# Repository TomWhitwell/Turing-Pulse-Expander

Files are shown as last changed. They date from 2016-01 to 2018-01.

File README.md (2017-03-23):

# Turing-Pulse-Expander
Rev 2 Turing Pulse Expander 

This is a slightly updated version of the Turing Machine Pulse Expander, with more outputs. It uses SMD components, but is still a very easy build. 

BOM: 

- 1 x 4081 Quad AND Gate, SO14 package 
- 11 x 3mm LEDs 
- 11 x 1k resistors, 1206 package 
- 11 x 2k resistors, 1206 package (These are the LED protection resistors, if you're using high intensity LEDs they should be a different value)
- 11 x [Thonkiconn](https://www.thonk.co.uk/shop/thonkiconn-3-5mm-jack-sockets-x50/) sockets
- 1 x 16 Pin Header 2x8 (for example 649-67997-216HLF from Mouser)
- 1 x Ribbon cable

There is no panel yet in this repository.

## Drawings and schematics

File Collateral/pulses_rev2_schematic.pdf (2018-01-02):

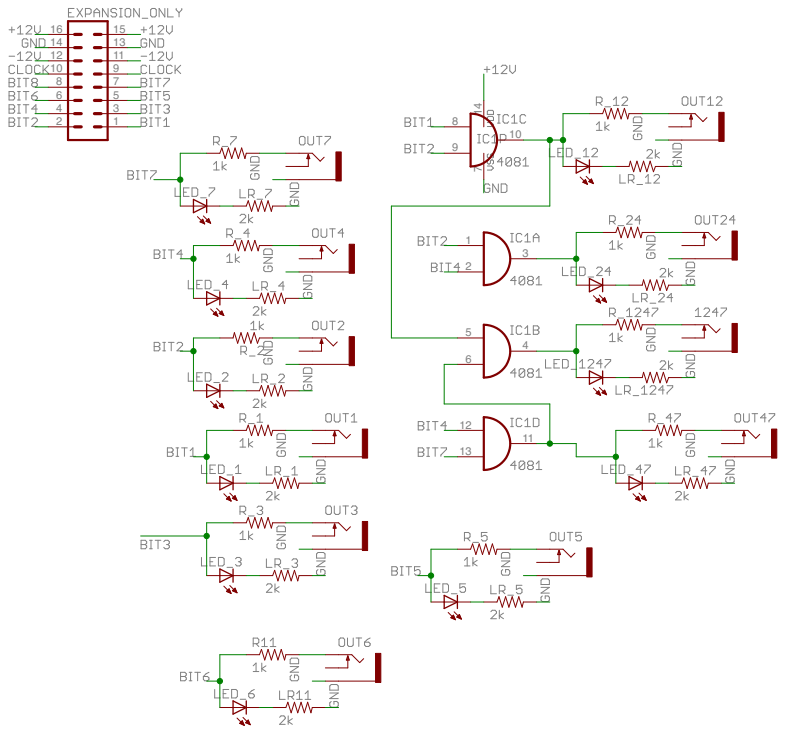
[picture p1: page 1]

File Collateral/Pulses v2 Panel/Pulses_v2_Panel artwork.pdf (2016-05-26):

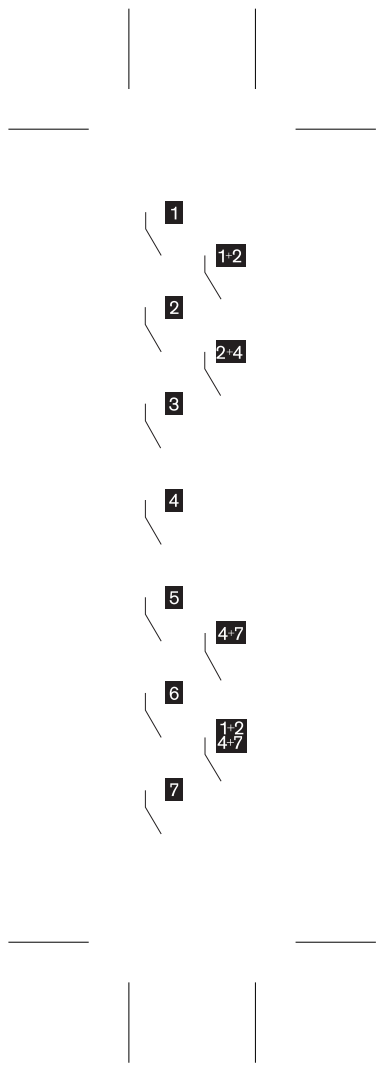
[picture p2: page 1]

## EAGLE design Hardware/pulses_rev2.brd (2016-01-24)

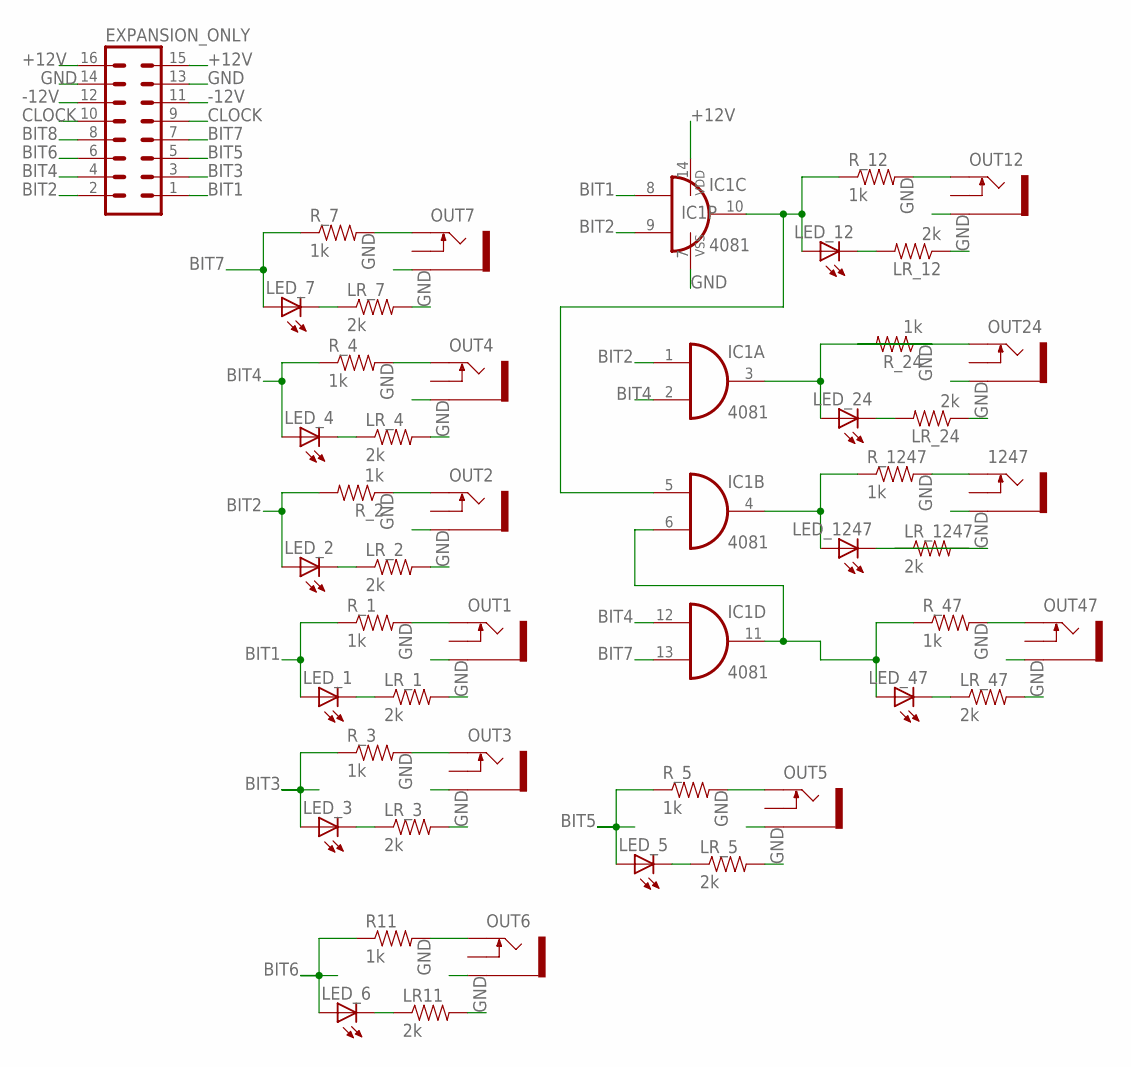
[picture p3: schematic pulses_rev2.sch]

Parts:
1247: THONKICONNNEW; WQP-PJ301M-12_JACK
EXPANSION_ONLY: MA08-2
IC1: 4081; SO14
LED_1, LED_2, LED_3, LED_4, LED_5, LED_6, LED_7, LED_12, LED_24, LED_47, LED_1247: LED3MM
LR11: 2k; 1206
LR_1, LR_2, LR_3, LR_4, LR_5, LR_7, LR_12, LR_24, LR_47, LR_1247: 2k; 1206
OUT1, OUT2, OUT3, OUT4, OUT5, OUT6, OUT7, OUT12, OUT24, OUT47: THONKICONNNEW; WQP-PJ301M-12_JACK
R11: 1k; 1206
R_1, R_2, R_3, R_4, R_5, R_7, R_12, R_24, R_47, R_1247: 1k; 1206

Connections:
+12V: EXPANSION_ONLY.15, EXPANSION_ONLY.16, IC1.14 (VDD)
-12V: EXPANSION_ONLY.11, EXPANSION_ONLY.12
BIT1: EXPANSION_ONLY.1, IC1.8 (I0), LED_1.A, R_1.1
BIT2: EXPANSION_ONLY.2, IC1.1 (I0), IC1.9 (I1), LED_2.A, R_2.2
BIT3: EXPANSION_ONLY.3, LED_3.A, R_3.1
BIT4: EXPANSION_ONLY.4, IC1.2 (I1), IC1.12 (I0), LED_4.A, R_4.1
BIT5: EXPANSION_ONLY.5, LED_5.A, R_5.1
BIT6: EXPANSION_ONLY.6, LED_6.A, R11.1
BIT7: EXPANSION_ONLY.7, IC1.13 (I1), LED_7.A, R_7.1
BIT8: EXPANSION_ONLY.8
BIT9: IC1.5 (I0), IC1.10 (O), LED_12.A, R_12.1
BIT10: IC1.3 (O), LED_24.A, R_24.1
BIT11: IC1.4 (O), LED_1247.A, R_1247.1
BIT12: IC1.6 (I1), IC1.11 (O), LED_47.A, R_47.1
CLOCK: EXPANSION_ONLY.9, EXPANSION_ONLY.10
GND: 1247.P$3_SLEEVE (SLEEVE), EXPANSION_ONLY.13, EXPANSION_ONLY.14, IC1.7 (VSS), LR11.2, LR_1.2, LR_2.2, LR_3.2, LR_4.2, LR_5.2, LR_7.2, LR_12.1, LR_24.1, LR_47.2, LR_1247.1, OUT1.P$3_SLEEVE (SLEEVE), OUT2.P$3_SLEEVE (SLEEVE), OUT3.P$3_SLEEVE (SLEEVE), OUT4.P$3_SLEEVE (SLEEVE), OUT5.P$3_SLEEVE (SLEEVE), OUT6.P$3_SLEEVE (SLEEVE), OUT7.P$3_SLEEVE (SLEEVE), OUT12.P$3_SLEEVE (SLEEVE), OUT24.P$3_SLEEVE (SLEEVE), OUT47.P$3_SLEEVE (SLEEVE)
unnamed: OUT1.P$1_TIP (TIP), R_1.2
unnamed: LED_1.K (C), LR_1.1
unnamed: OUT12.P$1_TIP (TIP), R_12.2
unnamed: OUT2.P$1_TIP (TIP), R_2.1
unnamed: LED_2.K (C), LR_2.1
unnamed: LED_12.K (C), LR_12.2
unnamed: OUT4.P$1_TIP (TIP), R_4.2
unnamed: LED_4.K (C), LR_4.1
unnamed: OUT24.P$1_TIP (TIP), R_24.2
unnamed: OUT7.P$1_TIP (TIP), R_7.2
unnamed: LED_7.K (C), LR_7.1
unnamed: LED_24.K (C), LR_24.2
unnamed: 1247.P$1_TIP (TIP), R_1247.2
unnamed: LED_1247.K (C), LR_1247.2
unnamed: OUT3.P$1_TIP (TIP), R_3.2
unnamed: OUT47.P$1_TIP (TIP), R_47.2
unnamed: LED_47.K (C), LR_47.1
unnamed: LED_3.K (C), LR_3.1
unnamed: OUT5.P$1_TIP (TIP), R_5.2
unnamed: LED_5.K (C), LR_5.1
unnamed: OUT6.P$1_TIP (TIP), R11.2
unnamed: LED_6.K (C), LR11.1

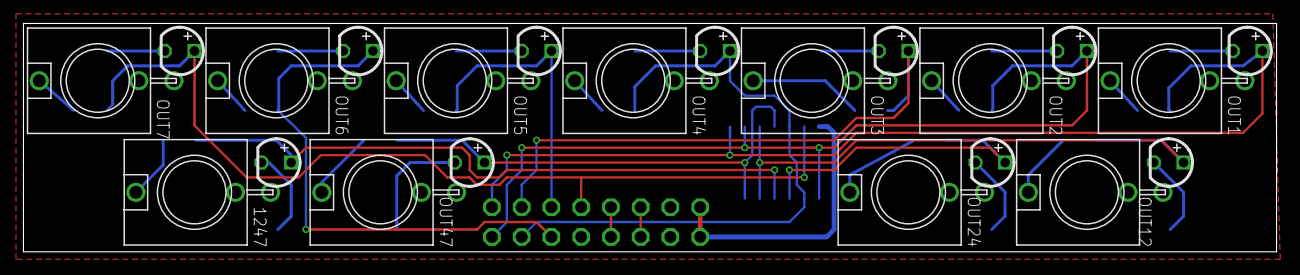
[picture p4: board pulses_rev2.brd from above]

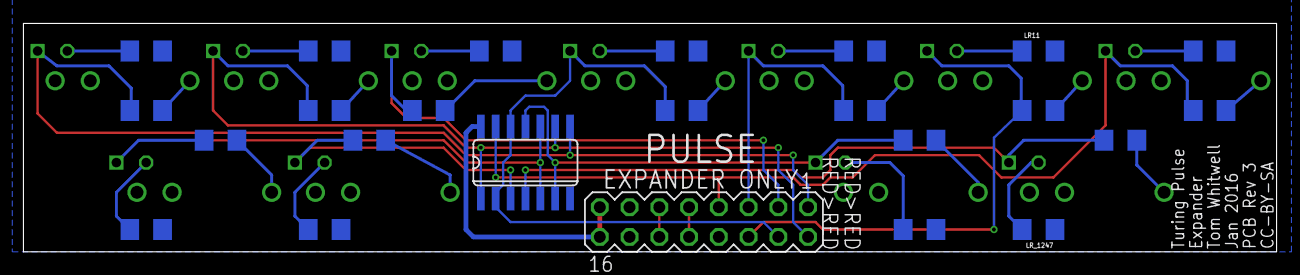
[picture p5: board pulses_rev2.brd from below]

Board: 4 copper layers, 107.0 x 19.5 mm, 46 parts (24 on the bottom side), 37 nets.

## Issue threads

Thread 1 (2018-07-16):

professionally built Turing Machine acting crazy when DIY Pulse is connected

tbffbt, 2018-07-16:
Hello,

I built a DYI Pulse for my professionally built Turing Machine. What happens is:

as soon as I plug the ribbon cable coming out of Turing's back Pulse pinout into the Pulse expander the Turing seemingly stops randomizing voltages, and the notes resulting from it are all the same, with very slight variations, that sound more like a slight detuning. I've also noticed that it's impossible to zero-out Turing's feed using the Write switch, I may even hold the switch down for as long as I'd like until no pulse comes out of it, but as soon as I let go of it Turing starts spitting sequenced notes (I can give a more detailed description upon request).

the Pulse expander on the other hand seems to be working just fine, spitting pulses according to these random uncontrollable pulses generated by the Turing.

at first I thought I had fried the SMD on the Pulse during assembly and ordered replacement chips, only to solder in a new one and run upon the same exact behavior.

has this issue been documented before? I don't know which of the modules is the faulty one. I've tested all of the resistors on the Pulse using a Multimeter and they all seem fine, even replaced the SMD, and the Turing never showed any signs of irregularity in its functioning, in fact the person who built it did a nice and clean job with the soldering and all, from what I can tell.

any ideas on what might be causing this strange behavior? help!

att

Tomaz

TomWhitwell, 2018-07-16:
Have you checked the ribbon cable to the expander is the correct way around?

tbffbt, 2018-07-16:
hi Tom, thanks for the reply

I did check the cable yes. Red goes to Red!

tbffbt, 2018-08-06:
I've just tried soldering a third new 4081 chip, to no avail. cleanest solder yet, quick and painless. And the issue is indeed with the Pulses expander, I tried using it with a friend's Turing Machine and as soon as I connected the ribbon cable his TM presented the same behaviors. Also tried another ribbon cable, but still the same. I've ran out of ideas.

Closed 2023-01-09.

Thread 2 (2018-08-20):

LED 7 continuous not pulsing

1986Mrk, 2018-08-20:
Dear Tom, dear Github,

Yesterday I built the Pulse Expander. When I connected the module to the Turing Machine all seemed fine, until the 7th LED started flickering dimly. After 15 seconds the LED was burning bright, no flickering anymore.
My knowledge of circuits is close to nothing.. Could a component be burned? Do you have an idea which component it might be?
Some LEDs burn a bit brighter than others; is this normal?

TomWhitwell, 2018-08-20:
Hi @1986Mrk that sounds like something is wrong. The LEDs all have the same power and the same resistors, so they should be (at least to the human eye) the same brightness.
Start by double - checking your soldering, there could be a short circuit somewhere. If you can, post high-res images of the front and back of the board here.

1986Mrk, 2018-08-20:
Thanks for your reply Tom. I will check this later today and will post images of the front and back of the board.

1986Mrk, 2018-08-21:
Goodmorning Tom,

Yesterday I measured the resistors with a multi meter; one 2K resistor gave 0,8K instead (brighter LED). Some others started around 1,5K and slowly went up in resistance re-soldered those and all is fine now! Thanks for the design of these modules, gonna use them a lot!

TomWhitwell, 2018-08-21:
That’s good to hear - enjoy!

Closed 2018-08-21.

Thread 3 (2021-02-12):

Mk2 - Led 7 always on

Madsiboy1995, 2021-02-12:
Hey Tom
Thanks for some great modules. Just finished building Turing Machine + Pulses MK2.
Unfortunately LED #7 is continuous and not pulsing like the rest.

Is there an explanation for this?

Best regards

TomWhitwell, 2021-02-13:
Hi, that must be annoying. This isn’t a problem I’ve heard of before.

A few ideas about how to approach it. Try connecting the pulses to the other (gate) output on the back of the Turing. You’ll see the lights stay on for the whole step length (rather than blinking with the clock).

If LED 7 is flashing on and off with the others, the problem is in the Turing module. If it is permanently on, the problem is probably in the expander.

If the problem is in the expander - that’s good, because it’s a very simple module.

Are the LEDs on the right working as you’d expect? Does step 7 output a changing pulse, or is if always on?

Madsiboy1995, 2021-02-13:
Wow Tom! So fast response.

I've tried changing out the resistors, but in the end it turned out it was a small shortage at the chip.
Eveything is working now!

Suuupedepoissooon, 2022-08-29:
Hello everybody !

I am experiencing the same issue, but with the "4+7" LED -> the LED is always on and no pulse is getting out of the step.
I tryed the other output of the turing machine and there is no difference, so the problem seems to be with the expender.
I double checked the chip but it seems I don't have the same issue as Madsiboy. I also replaced the two resistances related to the step but nothing changed.

Any idea ? Best regards

Closed 2021-02-13.

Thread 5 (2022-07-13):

Problem with pulses on the right side of the unit

SimonSmalley, 2022-07-13:
Hi,

I'm very new to soldering electronics and I just finished building my DIY pulses module. It all works aside from I'm getting no signal or lights on the 1+2, 4+7 and 1+2 4+7 outputs.

I did make a mistake along the way with this build and one of the resistor pads came off the board. I made a fix by connecting the resistor to the correct terminal with a small wire. I tested with a multi-meter and all seems fine.

Not really sure what to try next so if anyone can offer any help that would be great.

Many thanks,
Simon

SimonSmalley, 2022-07-13:
All sorted now. I double checked the connections on the chip and it worked.

Closed 2022-07-14.

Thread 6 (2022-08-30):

Pulse MKII - "4+7" LED always on + step not sending trig

Suuupedepoissooon, 2022-08-30:
Hello everybody !

I am experiencing the same issue as mentionned by Madsiboy (closed), but with the "4+7" LED -> the LED is always on and no pulse is getting out of the step.
I tryed the other output of the turing machine and there is no difference, so the problem seems to be with the expender.
I double checked the chip but it seems I don't have the same issue as Madsiboy. I also replaced the two resistances related to the step but nothing changed.

Any idea ? Best regards

TomWhitwell, 2022-08-31:
A few things you could try:
- Post clear photos of back and front of the boards so we can have a look
- Try removing the chip to see if anything changes - is led 7 still lit

Suuupedepoissooon, 2023-01-09:
Hi Tom, you probably never received my previous answers because I send you several emails.

Here is my latest answer :
I removed the chip as you asked and no the led 7 does not lit anymore.
What do you suggest ?

Thx Tom

TomWhitwell, 2023-01-09:
So - can't remember, have you replaced the 4081 already?

Suuupedepoissooon, 2023-01-09:
No, I didn't have any new 4081 to replace it. But anyway, it seems that I accidentally damaged a stip on the PCB when I removed the old one...

Closed 2023-01-09.

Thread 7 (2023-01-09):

PULSES MKI output 4 not working, and 2+4 , 1+2 4+7 not working

antibiotico01, 2023-01-09:
Just bought a used Turing machine but it seems the PULSES module is not working very good,

outputs 1, 2, 7 and 1+2 are working

but outputs 4  and 2+4 , 1+2 4+7 combinations are not working

it seems the issue is around the 4 output

any advice to fix it?

TomWhitwell, 2023-01-09:
Hi, the schematic is here: https://www.musicthing.co.uk/Turing-Pulse-Expander/

There's not much to it, if 1+2 is working then the 4081 chip is at least partly alive + damaged 4081 couldn't explain why 4 is dead.

Check:
* the cable
* The soldering around 4 and the cable - a solder bridge to ground on pin 4 might explain the problem.

antibiotico01, 2023-01-10:
Dear Tom thanks a lot for the advice, I will review it !

antibiotico01, 2023-01-10:
well it seems that the soldering and the cable are ok, I´ve checked with a multimeter and everything is fine
is a through hole pcb (version I) so it is not complicated, no smd components
 so I think it is the chip maybe

antibiotico01, 2023-01-10:
I attach a video of the behavior,  4 and 2+4 , 1+2 4+7 combinations are not working
oly 1, 2, 7 and 1+2 are working
although 7 seems a little bit dimmer than the others

https://user-images.githubusercontent.com/122239826/211676463-29b67d52-d481-4c8e-bb8b-814b5fdc5b01.mov

nickolaytsirkunov, 2023-01-23:
I had the same problem with PULSES: outputs "1+2" and "1+2+4+7" were not working and some of the other outputs were dimmer.
IC cd4081 was fault. Everything begins to work properly after I've change IC.

antibiotico01, 2023-01-25:
THAKS A LOT! must be the chip I´ll try to change it thanks for the advice [nickolaytsirkunov]

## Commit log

2016-01-24 Initial upload, design complete for first prototype
    [pulses_rev2.brd, pulses_rev2.sch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]
2016-01-25 Non functional schematic tweaks
    [pulses_rev2.sch]

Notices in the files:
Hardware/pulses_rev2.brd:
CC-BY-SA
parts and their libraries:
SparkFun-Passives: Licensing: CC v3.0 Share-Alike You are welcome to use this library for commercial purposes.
